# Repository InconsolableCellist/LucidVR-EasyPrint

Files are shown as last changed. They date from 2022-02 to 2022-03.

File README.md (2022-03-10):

# LucidVR-EasyPrint

## Description

Open 3D designs for the LucidVR glove project that are designed to be easier to print and use less filament.

I ran into numerous issues when trying to print the standard LucidVR 4.0 and 4.1 designs, and because the Solidworks files weren't available I reimplemented those designs and made changes intended to improve them. My designs printed far more reliably on my printer (Robo 3D R1+ w/ PLA @ 190°C, 0.4mm nozzle, heated bed at 60°C) and require something like 25% less filament. They also removed points of failure I had, like the snap cover not working, thicker walls on the part of the tensioner that retains the spring, and more fillets for general strength improvements.

## Parts

### Tensioner and Cover

This part replaces "Tensioner_WLPot" and "SpoolCover_open.STL"

When I tried to print those designs the snap interface would get distorted and the nozzle of my older printer would hit the part itself, causing it to distort or break free from the print bed. The snap interface itself was also thin and fragile and it seemed unnecessary to have it separated into two parts.

This design integrates the cover into the tensioner and just requires the "HapticSpool.STL" to be placed on top.

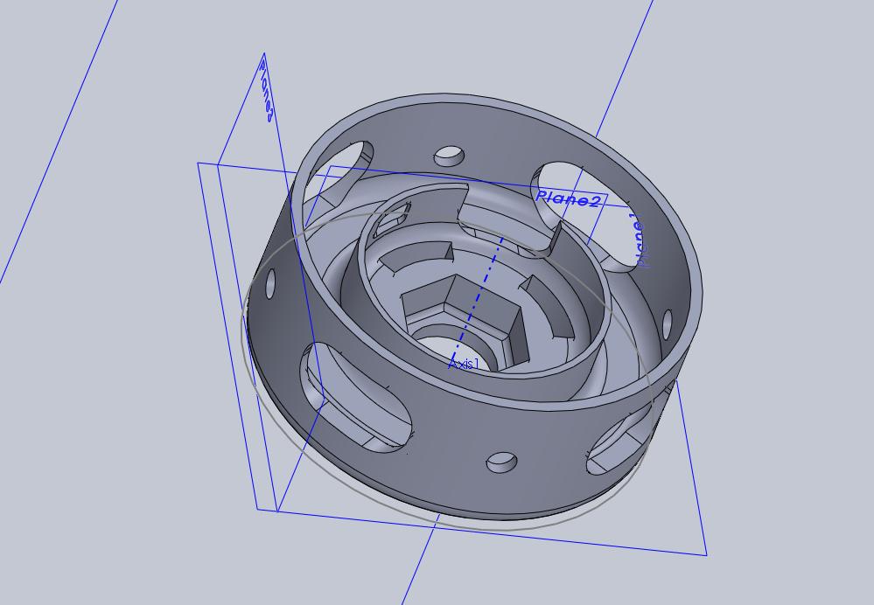
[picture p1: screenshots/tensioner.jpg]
Tensioner


### New slide mount 

This part replaces "WLPotSLideHolder_Proto4.1.STL" (and previous versions). It fits the Tensioner and Cover in this repo and uses less filament

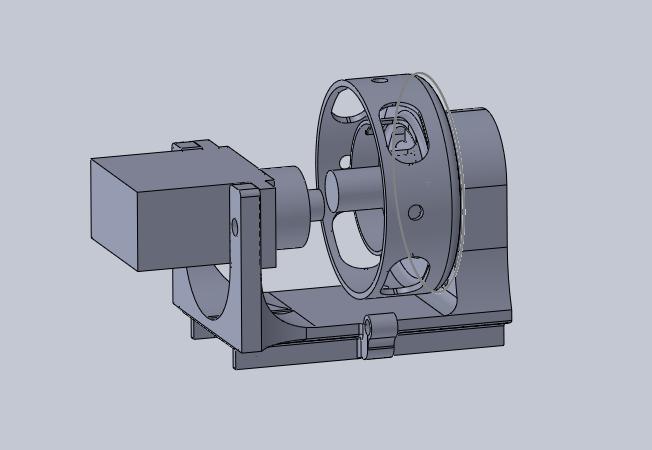
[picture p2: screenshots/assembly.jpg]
Slide mount assembly


### End caps with no overhangs

This part replaces "Proto3_EndCap.STL"

The stock end caps would peel away from my heated bed and had large overhangs that didn't seem necessary.

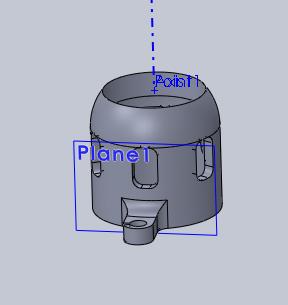
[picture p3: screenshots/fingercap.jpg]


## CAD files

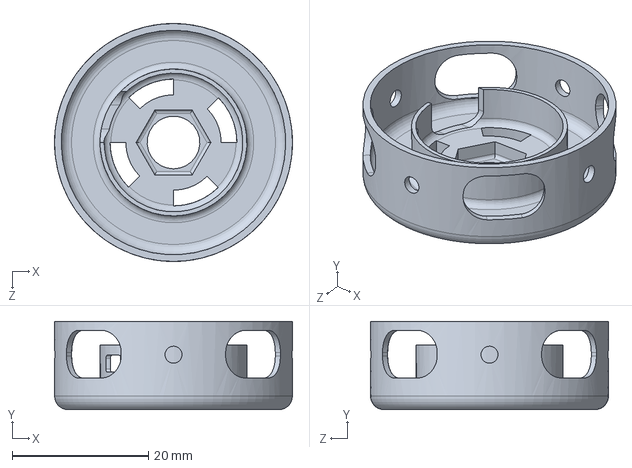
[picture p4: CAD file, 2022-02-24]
hardware/Tensioner.SLDPRT
35.0 x 13.0 x 35.0 mm

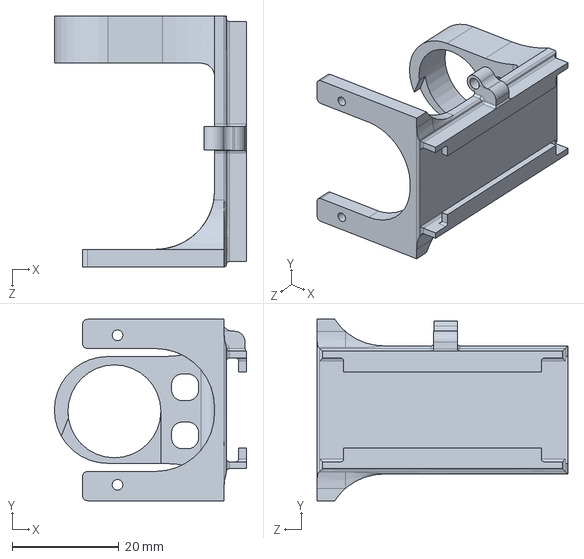
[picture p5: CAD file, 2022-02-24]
hardware/Slide Mount.SLDPRT
36.0 x 34.0 x 47.0 mm

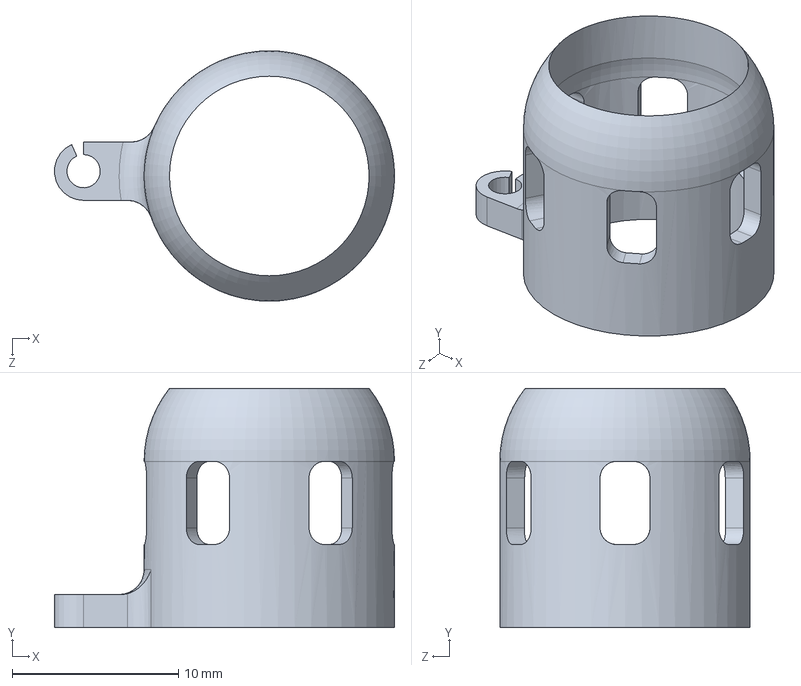
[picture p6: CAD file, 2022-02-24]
hardware/Finger Cap.SLDPRT
20.4 x 14.4 x 15.1 mm

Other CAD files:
hardware/Finger Cap.STL
hardware/Slide Mount.STL
hardware/Tensioner.STL

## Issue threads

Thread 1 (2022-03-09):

Slide Mount Potentiometer Type

hitchhiker4200, 2022-03-09:
Hello and thanks so much for these designs!  I did have a bit of confusion regarding the Slide Mount and the type of potentiometer it was intended for.

You have indicated in the description that it replaces the GreenPotSLideHolder_Proto4.1.STL from the LucidGloves repository, but it appears to be designed to replace the larger WLPotSlideHolder_Proto4.1.STL.  It took me a few minutes to figure this out, and since I have the green pots ordered, I'll probably pick up your design and modify it.

Just thought I would let you know.

Thanks again!

InconsolableCellist, 2022-03-10:
Whoops, you're right. I updated the README to fix those names. I wasn't able to get the greenpots so I only used the larger ones, "WL Pots."

It'd be awesome if you modify it for the green pots! Just make a PR when you can. Also let me know if the design works for you.

The LucidVR design in general still has lots of room for improvement. I haven't been able to make a glove that's reliable or sturdy enough for actual VR use rather than a proof of concept.

Closed 2022-03-10.
